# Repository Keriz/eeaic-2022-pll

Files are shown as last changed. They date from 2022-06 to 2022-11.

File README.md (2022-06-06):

# EEAIC 2022

Repository for documentation purposes of our project in the ETHZ course EEAIC, edition 2022.

We implemented the paper from Faroni et al. [1] to implement a Class-D VCO as part of a whole PLL.
Overall , we achieved a FoM @ 10 MHz of -190.14 dBc/Hz, with a total power budget of less than 4mW and a reference clock of 31.25MHz.

[1] L. Fanori and P. Andreani, "Class-D CMOS Oscillators," in IEEE Journal of Solid-State Circuits, vol. 48, no. 12, pp. 3105-3119, Dec. 2013, doi: 10.1109/JSSC.2013.2271531.

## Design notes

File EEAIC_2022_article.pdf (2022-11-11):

# EEAIC 2022 PLL - Final report

Xi Chen, Kyuik Cho, Garðar Eðvaldsson, Marwan Abdelaziz Ibrahim, Guillaume Thivolet

I. INTRODUCTION
This paper presents the implementation of a Phase-Locked Loop (PLL) in the TSMC 65-nm CMOS process based off the Class-D oscillator introduced by Fanori and Andreani in [1]. Class-D oscillators produce less phase noise compared to the class-B/C architectures for the same power consumption, at the expense of higher power supply than their counterparts. This work looked at implementing a Class-D VCO in a realistic PLL design where nonidealities were also taken into account. Current consumption, phase noise and figure-of-merits were derived and compared with the reference paper. The PLL runs at a supply voltage of 1.2V with a total power consumption of 3.837mW, with the VCO consuming 1.947mW which is substantially lower than the 4mW reported in the reference paper. The VCO exhibits a phase noise of -141.312 dBc/Hz at 10MHz, with a tuning range of 4%.

II. DESIGN SPECIFICATIONS
In order to design a realistic design, some metrics needed to be chosen.
Parameter | Value | Unit
fvco | 4 | GHz
fref | 31.25 | MHz
Ptot | <4 | mW
F oMV CO | <-191 | dBc/Hz
ϕn,vco @ 10MHz | <-143.5 | dBc/Hz

TABLE I: Initial design criteria for the PLL

III. PLL DESIGN AND COMPONENTS.
We aimed for a Type-II PLL using a fully analog control circuitry. In the following subsections, we will go through the choice of the components used for the realisation of the design.
PFD | Charge
Pump | LPF

1/128

VCO

REF
31.25MHz

FEED

4GHz

Vout | Vcont

QA

QB

Class-D CMOS Oscillator

Fig. 1: Block diagram for the PLL design.

A. Phase Frequency Detector (PFD)
The PFD, inspired from [2], has a role of generating switch signals Qa and Qb for the charge pump depending on which

Fig. 2: PFD Schematic

clock is lagging or leading. Those states are generated on rising edges of Clkref and Clkdiv respectively. If Clkref is leading, we first generate a pulse Qa that is pushing current into the low pass filter to raise the VCO control voltage Vcont. If Clkdiv is rising first, Qb is turned on first and the charge pump will pull current to ground, decreasing Vcont. The pulses are reset when the other clock has a rising edge.

B. Charge Pump (CP)

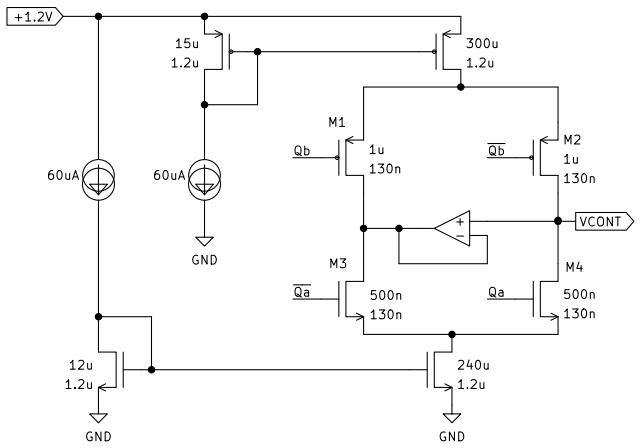
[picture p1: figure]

Fig. 3: Charge Pump Schematic

As we can see in Fig. 3, a simple current steering concept was used in order to keep a constant current flow at all times for better output control. Upon Qa being high, the transistor M1 turns off and M3 is turned on, injecting current to the loop-filter. Upon Qb being high, it would have the opposite to Qa, turning off M3 and turning M4 on, depleting current from the loop-filter as it would be connected to ground. If Qa and Qb are both off, the left branch is still drawing current. This keeps the Vds node voltages of the PMOS and NMOS current sources transistor constant. This is necessary in order to keep the parasitic capacitance Cds of all transistor fully charged at all times, instead of depleting them due to the charge sharing nature of the capacitance in the loop-filter. In order to do so, the operational amplifier between the two branches keeps Vcont constant on both sides of the branches and keeps the parasitic capacitances charged. Therefore the charge pump and the loop-filter charge sharing is minimised which improves dynamic current matching. CP phase noise is primarily given by the channel thermal noise component of the current source ¯i
2
d = 4KT γgm.
C. Loop Filter (LF)
In order to ensure stability of the PLL loop dynamics described in section V, a higher order filter needs to be used. In this project, a simple 2nd order filter was designed using two capacitors and a resistor.

Fig. 4: 2nd order loop filter schematic

D. Frequency Divider (FD)

Fig. 5: Frequency divider block diagram

The frequency divider is using 3 daisy chained TSPCs with a division factor of 2, along with 4 daisy chained flip-flops with a division factor of 2. This gives in total a division factor of 2

7 = 128. The full schematic and operation is available in Appendix VIII-B.
The TSPC blocks are responsible for frequency division of high frequency clock signals, whereas the flip-flops are more suitable for slower signals, since the TSPC topology fails at slower clock frequencies due to high leakage currents. Finally, the output of the last divider stage goes into the PFD block, which completes the PLL Loop.

IV. CLASS-D VCO
The main building block of every PLL is the VCO. This project was aimed at integrating the Class-D oscillator as envisioned by [1] and benchmark its performances in a Type-II PLL.
In Fig. 6 is the schematic of the implemented VCO for the PLL. It shows discrepancies from the ideal VCO as we needed to account for parasitics in order to simulate a realistic environment.
1) Inductor Model: In order to simulate a realistic inductor in the VCO, a simplified model needed to be realised. By choosing an inductance of 500pH, and a Q-factor of 15 (which is realistic for a moderately designed inductor), other parasitic elements can be calculated as follows. The quality factor for an ideal inductor is:
Q =

ωL
R

(1)

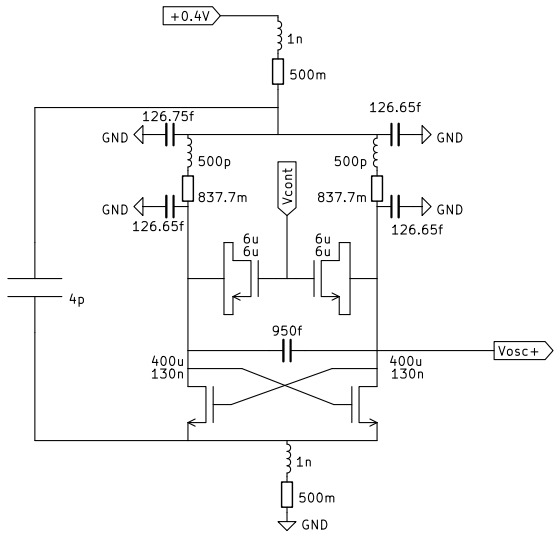
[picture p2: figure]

Fig. 6: Class-D VCO Schematic

and by simplifying for R, we can calculate the parasitic resistance:
R =

ωL
Q
= 837.7mΩ | (2)

where ω = 2 · π · fosc, where fosc = 4GHz. Now we state that we have a oscillating harmonic at 5 times the oscillation frequency, and using:

ωH = 5 · ω =

1
√
LC | (3)

and solving for C, we get:

C =

1
ω

2
HL
= 126.65fF | (4)
2) Wire Bonding: Because of the severe supply pushing of the Class-D oscillator, it is of extreme importance to simulate the off-chip wire bonding instead of using a clean power supply in order to see the supply pushing effect on the output of the oscillator. In order to simulate a realistic wire bonding, an inductor of 1nH and a resistor of 500mΩ were attached on both ground and Vdd. Along with the off-chip parasitics, a capacitor of 4pF was added between the rails in order to suppress the harmonics introduced by the parasitics.
A. Tuning Range
In order to control the oscillation frequency of the oscillator, a way to change either the inductance or the capacitance of the LC tank has to be developed. In a real design, it is extremely hard to change the inductance as the inductor has a fixed size (area of metal on a substrate), so the easiest and most-common choice is to vary the capacitance of the LC-tank using a socalled varactor. Different configurations can be used in order to adjust the capacitance of the LC-tank. In this report, two transistors were chosen in a back-to-back configuration, by using their parasitic capacitance when operated in the triode region. The control voltage from the charge pump (Vcont) was connected to the gates of both transistors, and their bulk (drain, source and body) were connected to the differential output ports of the VCO. By doing so, an acceptable tuning range could be chosen.

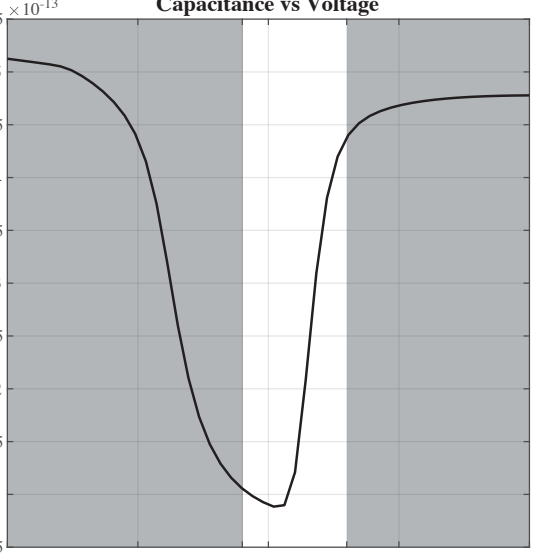
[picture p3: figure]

-2 | -1 | -0.2 0 | 0.6 | 1 | 2
V

## gs [V]

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
## Capacitance [F]

# 10⁻¹³ Capacitance vs Voltage

Fig. 7: Capacitance of tuning varactors plotted over applied voltage

As we can see from Fig. 7, the white area of the capacitance curve is the available working range of capacitance with the given oscillation amplitude and the given control voltage amplitude. Due to the asymmetrical nature of the Class-D oscillations, the simple formula ωosc = √

1
LC cannot be used
in order to determine the running frequency of the oscillator. A more elaborated analysis needs to be carried out [1], but a simple simulation can also suffice by simply sweeping the control voltage and simultaneously plotting the oscillation frequency fosc.
As we can see in Fig. 8 the range varies from [3.9-4.05] GHz, with the target frequency achieved when Vcont ≈ 630mV, resulting in a gain factor of Kvco = 220MHz/V. Special care needs to be taken when defining the range of Vcont, since it can sacrifice the closed loop stability of the PLL if too low.
B. Phase Noise and FoM
Phase noise can be described as random phase fluctuations at the output of the VCO. These fluctuations are caused by time-domain instabilities usually referred to as phase jitter. The phase noise is relative to the carrier frequency (fosc = 4GHz). As we can see in Fig. 9, we see the two main noise contributors to the phase noise, namely the upscaled flicker noise and the upscaled thermal noise. The corner where the thermal noise starts dominating over the flicker noise has been meticulously chosen at 180kHz. This will depend on the overall noise of the PLL’s performance which will be discussed better in section VI-A.

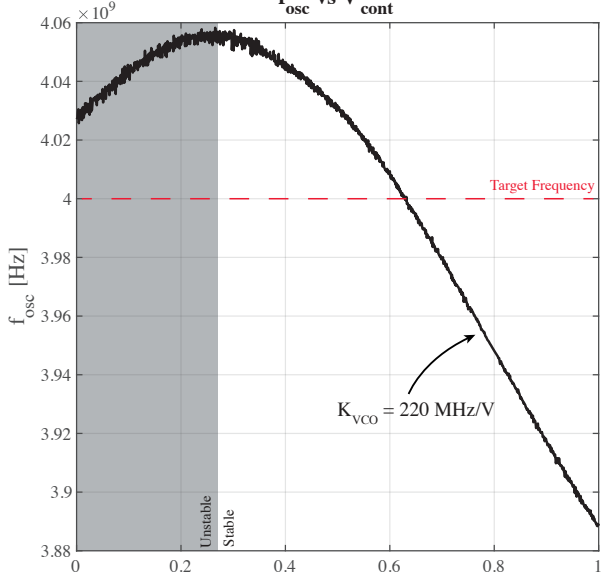
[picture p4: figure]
osc [Hz]; Unstable; Stable; KVCO = 220 MHz/V; Target Frequency

0 | 0.2 | 0.4 | 0.6 | 0.8 | 1

## Vcont [V]

10⁹ | f osc vs Vcont

Fig. 8: Oscillation frequency plotted over control voltage.

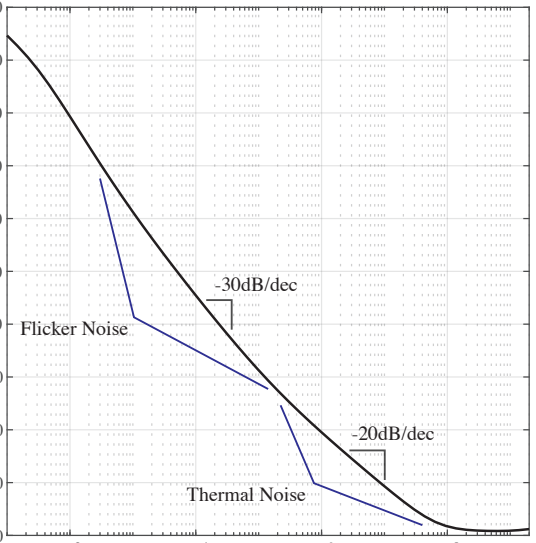
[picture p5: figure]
-20dB/dec; -30dB/dec; Flicker Noise; Thermal Noise

10² | 10⁴ | 10⁶ | 10⁸

## Offset Frequency [Hz]

-160

-140

-120

-100

-80

-60

-40

-20

0

20

40

## Phase Noise [dBc/Hz]

# VCO Phase Noise

Fig. 9: Phase noise of the Class-D VCO

In order to compare the VCO design with other designs on the market, the best benchmark is the Figure-of-Merit (FoM). Which compares the phase noise with the power needed to achieve that noise level. The FoM yields:

F oMvco = L(∆f) − 20log
fosc
∆f

+ 10log
Pvco

1mW
(5)
= −190.4dBc/Hz | (6)

where L(∆f) = −141.312dBc/Hz, ∆f = 10MHz, fosc =

4GHz and Pvco = 1.947mW.

C. PVT Variations

Due to PVT (Process-Voltage-Temperature) variations the PLL behaves differently than under ideal conditions. For the operation of the PLL, the biggest concern is the frequency tuning range of the VCO (see Fig. 10). In order to keep things simple, the only PVT variations of interest were the ones that had the most impact on the tuning range of the VCO. After running a bulk of initial simulations, three corners were chosen which displayed the highest range of tuning range.

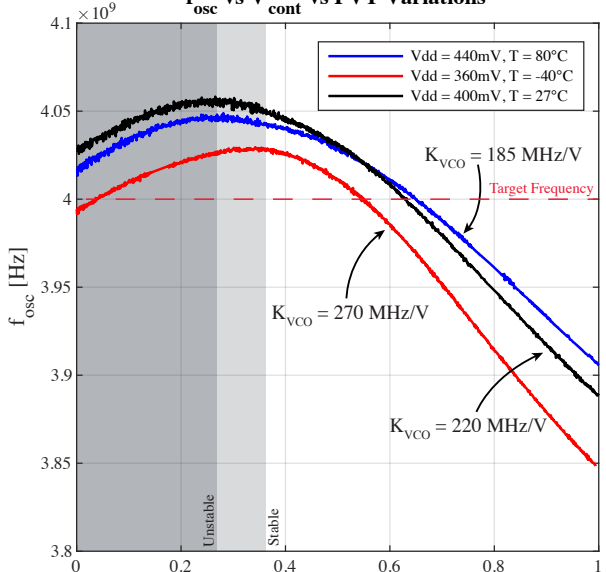
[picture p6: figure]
osc [Hz]; KVCO = 270 MHz/V; KVCO = 185 MHz/V; Target Frequency; KVCO = 220 MHz/V; Unstable; Stable

0 | 0.2 | 0.4 | 0.6 | 0.8 | 1

## Vcont [V]

10⁹ f

# osc vs Vcont vs PVT Variations

Vdd = 440mV, T = 80°C Vdd = 360mV, T = -40°C Vdd = 400mV, T = 27°C

Fig. 10: Frequency tuning range in terms of PVT variations.

As we can observe on Fig. 10, which shows the best and worst case scenarios for the PVT variations, the frequency gain of the VCO KV CO is heavily affected. This KV CO difference will impact the PLL noise characteristics and the loop bandwidth would ideally have to be adjusted again to match the new crossover frequency between the VCO and CP noise curves. However, it is possible to change ICP accordingly to conserve the same noise figure. Under PVT variations the frequency tuning crosses our target frequency of 4GHz, which indicates that the PLL will be able to lock under any conditions. It might however experience longer locking times at lower KV CO. We also see that in order for the PLL’s closed loop to be stable, the voltage control range must be limited between [0.35V-1V] when the VCO reaches higher KV CO while having a wider range of [0.25V-1V] for smaller KV CO.
As we can see from Fig. 11, the main change in phase noise because of PVT variations happens in the flicker noise region. That proves to be non-crucial since the transfer function for the noise of the VCO attenuates the flicker noise sufficiently.

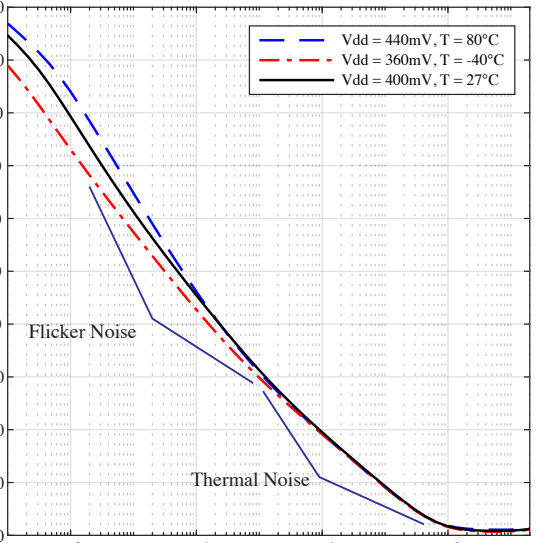
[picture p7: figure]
Vdd = 400mV, T = 27°C; Thermal Noise; Flicker Noise

10² | 10⁴ | 10⁶ | 10⁸

## Offset Frequency [Hz]

-160

-140

-120

-100

-80

-60

-40

-20

0

20

40

## Phase Noise [dBc/Hz]

# VCO Phase Noise and PVT Variations

Vdd = 440mV, T = 80°C Vdd = 360mV, T = -40°C

Fig. 11: Phase noise dependent on PVT variations

KVCO | Voltage | Temperature | Library
Nominal | 400mV | 27°C | tt_lib
High | 360mV | -40°C | sf_lib
Low | 440mV | 80°C | sf_lib

TABLE II: Chosen PVT corners for all simulations

V. PLL LOOP DYNAMICS
The PLL closed-loop dynamics (type-II system) is unstable as such, due to the non-existent phase margin as constant phase is -180°. This is usually compensated by the addition of a resistor R in between the CP and the VCO, which adds a zero for the loop stability. Additionally, we add another capacitor C2 in parallel to RC1 which is used to minimize the ripple on the control voltage.

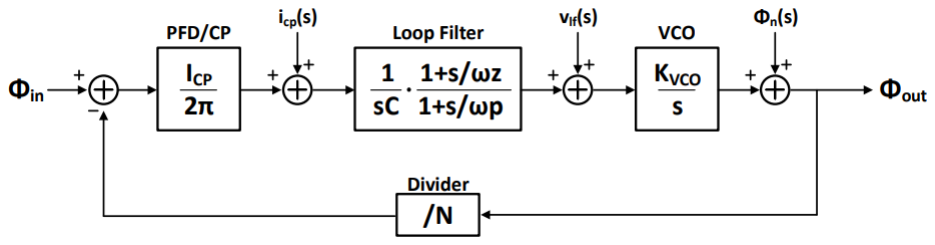
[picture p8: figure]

Fig. 12: PLL block diagram of transfer function

Ignoring the charge sharing capacitor, the closed-loop transfer function in the Laplace domain is given by:

HCL(s) =

IcpKV CO
2πC1

(sRC1 + 1)

s

2 +

Icp
2π

KV CO
N Rs +

Icp
2πC1

KV CO
N

(7)

We identify it to a second order system which is in the general case expressed as:

H(s) = | ωn
| 2
s

2 + ζωns + ωn
2

(8)

We define ωn and ζ in eq. 8 as such¹ :

ωn =

r
ICP
2πC1

KV CO
N

ζ =

R
2

r
ICP C1
2π

KV CO
N

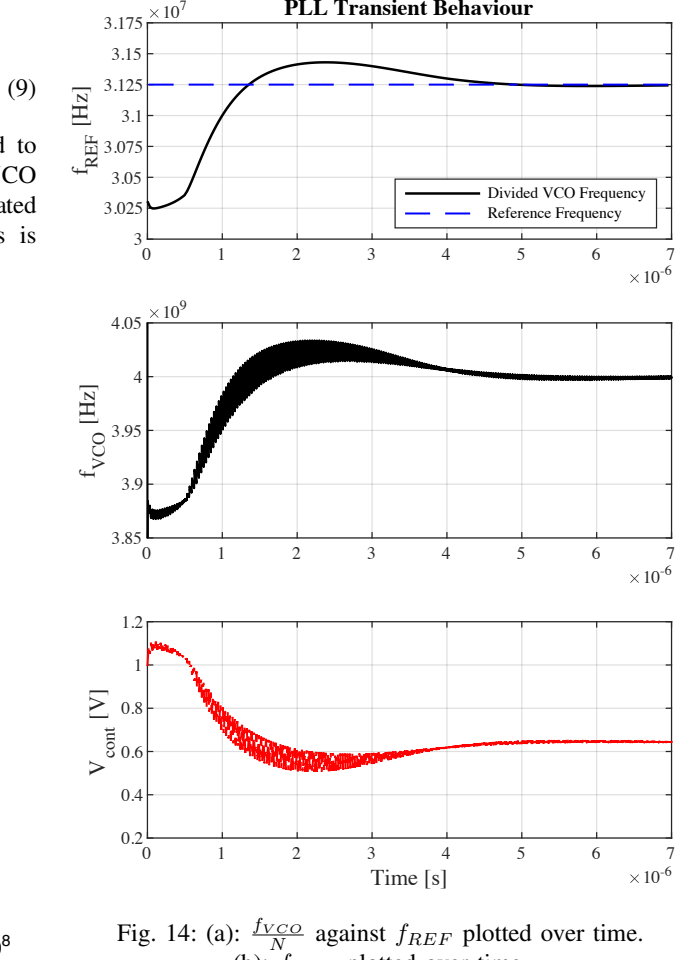
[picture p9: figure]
fREF [Hz]; Divided VCO Frequency Reference Frequency; fVCO [Hz]; Time [s]; Vcont [V]; Fig. 14: (a): fV CO N; against fREF plotted over time.

The PLL loop bandwidth of 281 kHz was optimized to match the crossover frequency of the charge pump and VCO phase noise curves and with a trade off between integrated jitter and lock time. The detailed optimisation process is explained in section VI.

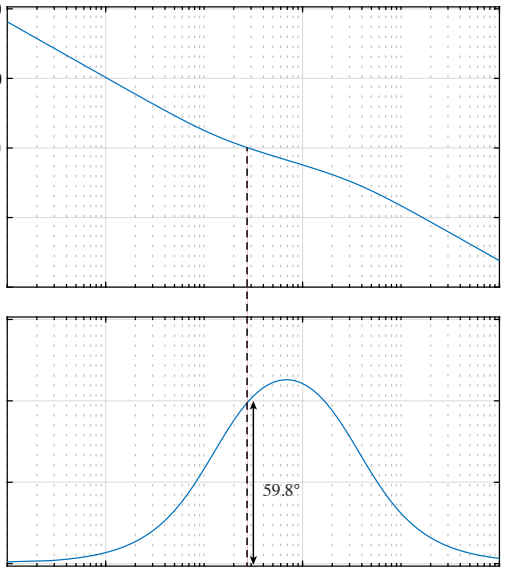
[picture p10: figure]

-100

-50

0

50

100

## Magnitude (dB)

10⁴ | 10⁶ | 10⁸

-180

-150

-120

-90

## Phase (°)

## PLL OL TF - Pm = 59.8° @ 281kHz

## Frequency (Hz)

Fig. 13: PLL Open Loop Dynamics

As we can see from Fig. 13, the open loop gain of the PLL dynamics has a phase margin of 59.8°at 281kHz.

VI. RESULTS

We ran a transient simulation of the whole PLL using Cadence Spectre. The resulting graphs are shown below.
As seen in Fig. 14, our PLL locks with success on the target frequency with a lock time of 5.05µs. In the further subsections, we will introduce the noise figures, the overall Figure-of-Merit for the entire PLL as well as the design resilience against PVT variations.
A. Noise
The biggest concern of a PLL is it’s noise contribution. Every block of the PLL introduces it’s own noise transfer functions, which in return contributes to the overall noise level of the PLL. In this work, the noise contribution of the reference clock is considered out of scope.

1KV CO = 220MHz/V, ICP = 1.2mA, N = 128, C1 = 233.9pF, R = 5.05KΩ

# 10⁷ PLL Transient Behaviour

(b): fV CO plotted over time. (c): Vcont plotted over time.

As we can see from Fig. 15, the the noise from the charge pump and and the VCO are nicely optimised in order to minimise the overall noise. Because of that, the overall noise is solely dominated by the loop-filter noise. Since the loop filter only consists of passive elements, it introduces a fixed noise floor that provides a hard limit to what can be achieved when it comes to noise optimisation.

B. Figure-of-Merit
By integrating the total noise from Fig. 15, the absolute RMS-jitter can be computed. The absolute RMS-jitter is defined as:

σ

2
t,P LL =

1
2π

2f

2/0 Z ∞

0

L(f) df | (10)

and the FoM of the PLL is defined as: F oMP LL = 10 log σt,P LL 1s
2 PP LL
1mW | (11)

With σt,P LL = 79.2fs and PP LL = 2.8974mW we get an FoM value of:

F oMP LL = −257.4dBc/Hz | (12)

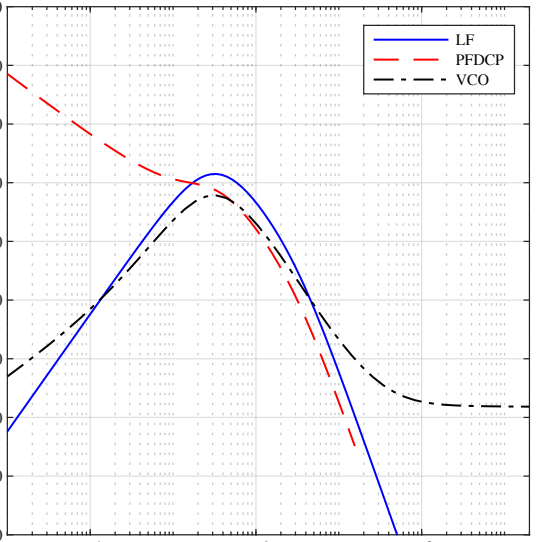
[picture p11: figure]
LF PFDCP VCO

10⁴ | 10⁶ | 10⁸

## Frequency [Hz]

-180

-170

-160

-150

-140

-130

-120

-110

-100

-90

## Phase Noise [dBc/Hz]

# PLL Phase Noise

Fig. 15: All noise contributions in the PLL.

C. PVT Variations

One of the biggest design criteria of every PLL design, is its robustness to PVT variations. By choosing the three important corners mentioned in Tab. II, we can predict the overall noise performance of the PLL.

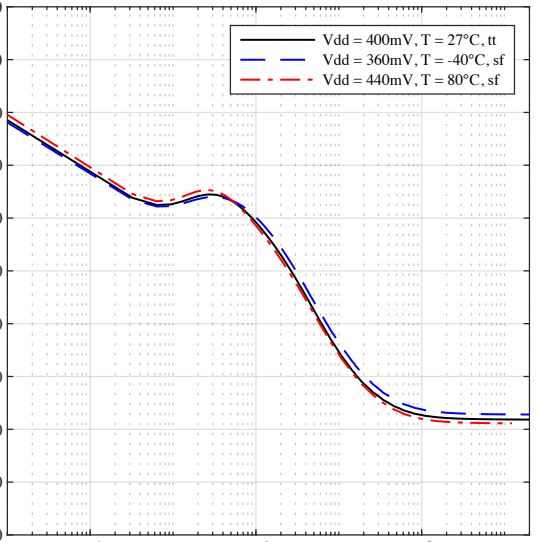
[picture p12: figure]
Vdd = 440mV, T = 80°C, sf

10⁴ | 10⁶ | 10⁸

## Frequency [Hz]

-180

-170

-160

-150

-140

-130

-120

-110

-100

-90

-80

## Phase Noise [dBc/Hz]

# PLL Phase Noise with PVT Variations

Vdd = 400mV, T = 27°C, tt Vdd = 360mV, T = -40°C, sf

Fig. 16: Total noise at different PVT corners

As we can see in Fig. 16, there is quite some noise deviation between the different corners.

KVCOCorner | Total Jitter | FoMPLL
Nominal | 79.2 fs | -257.40 dBc/Hz
High | 81.3 fs | -258.65 dBc/Hz
Low | 81.21 fs | -256.44 dBc/Hz

TABLE III: Total Noise of PLL w.r.t. to PVT variations

VII. CONCLUSION

This paper has presented a simple Type-II PLL design with a Class-D VCO [1]. The simulations have shown reasonable performance under all corner cases of interest and a decent FoM. Further improvements include increasing the tuning range of the VCO for a broader, which could entail adding coarse tuning, along with looking into more varactor topologies in order to tailor the tuning range even further than this present work does.

VIII. APPENDIX

A. Inverted Varactors

Instead of connecting Vcont to the gates of the two transistors, the transistors can be "turned around", and by connecting Vcont to their bulk (drain, source and body) and connecting the gate to the differential outputs (see Fig. 17) achieving a different frequency operating range.

Fig. 17: Two different varactor topologies.
Left: MOSFETs with Vcont wired to the common gates. Right: MOSFETs with Vcont wired to the common bulks.

Now by examining the tuning range of the VCO in Fig. 18, we can see substantial differences between the two varactor placements.
As we can see in Fig. 18, the voltage range of the control voltage is severely reduced compared to the varactor structure used in the current design. We can also see that in order to ensure closed loop stability of the PLL, the control range of Vcont must be meticulously chosen in order not to introduce a negative KV CO in the control loop.
B. TSPC

The True Single-Phase Clocking (TSPC) divide by 2 based circuit is shown in figure 19. It is a positive-edge triggered D-flip-flop with TSPC logic [3] which inverted output is tied to the D input.
We perform an analysis of the circuit to understand its functionality. We will initially assume that Q and CLK are 0. Node A and B will both be 1 and Q output will not change. On a rising edge of CLK, A will be floating. Node B will be

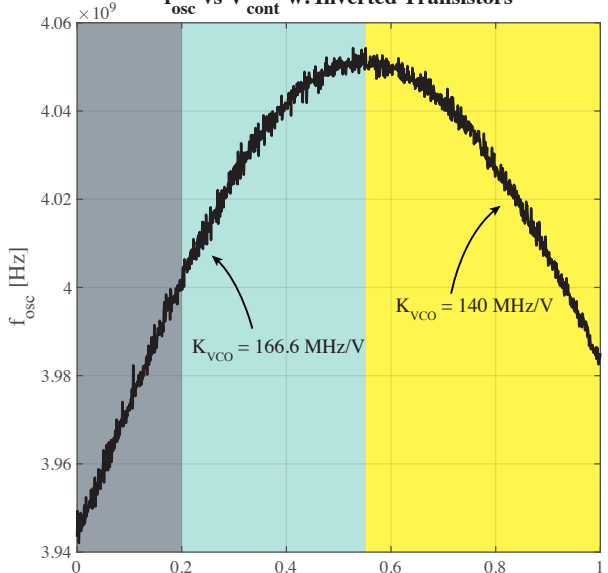
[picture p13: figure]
osc [Hz]; KVCO = 140 MHz/V; KVCO = 166.6 MHz/V

0 | 0.2 | 0.4 | 0.6 | 0.8 | 1

# Vcont [V]

10⁹ f

# osc vs Vcont w. Inverted Transistors

Fig. 18: Frequency behaviour of inverted varactors in the

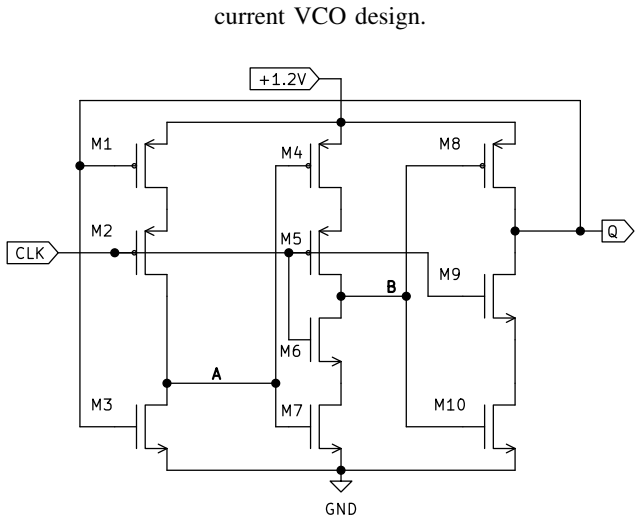
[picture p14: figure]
current VCO design.

Fig. 19: True Single-Phase Clocking (TSPC) used as a frequency divider

pulled to 0 which raises Q to 1. This change of output has no retroactive effect on the current state.
Now that Q is high, when CLK goes low the node A will have the logic value 0 and B will be floating, keeping the charge from last state, so the output stays constant. Finally, on a rising edge of CLK, node A will still be 0 and B still has the last state of 0. This pulls the Q output to 0, which effectively halves the clock period. This topology achieves relatively high speeds with low power dissipation.

REFERENCES
[1] Luca Fanori and Pietro Andreani. “Class-D CMOS Oscillators”. In: IEEE Journal of Solid-State Circuits 48.12 (Dec. 2013). Conference Name: IEEE Journal of Solid-State Circuits, pp. 3105–3119. ISSN: 1558-173X. DOI: 10.1109/JSSC.2013.2271531.
[2] Behzad Razavi. RF microelectronics. 2nd ed. Upper Saddle River, NJ: Prentice Hall, 2012. ISBN: 978-0-13-713473-1.
[3] Behzad Razavi. “TSPC Logic [A Circuit for All Seasons]”. en. In: IEEE Solid-State Circuits Mag. 8.4 (2016), pp. 10–13. ISSN: 1943-0582. DOI: 10.1109/MSSC.2016. 2603228. URL: http : / / ieeexplore . ieee . org / document / 7743122/ (visited on 06/01/2022).

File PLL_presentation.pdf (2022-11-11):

3.6.2022 | 1

## PLL based on a Class-D CMOS Oscillator

Xi Chen, Kyuik Cho, Garðar Eðvaldsson, Marwan Abdelaziz Ibrahim, Guillaume Thivolet

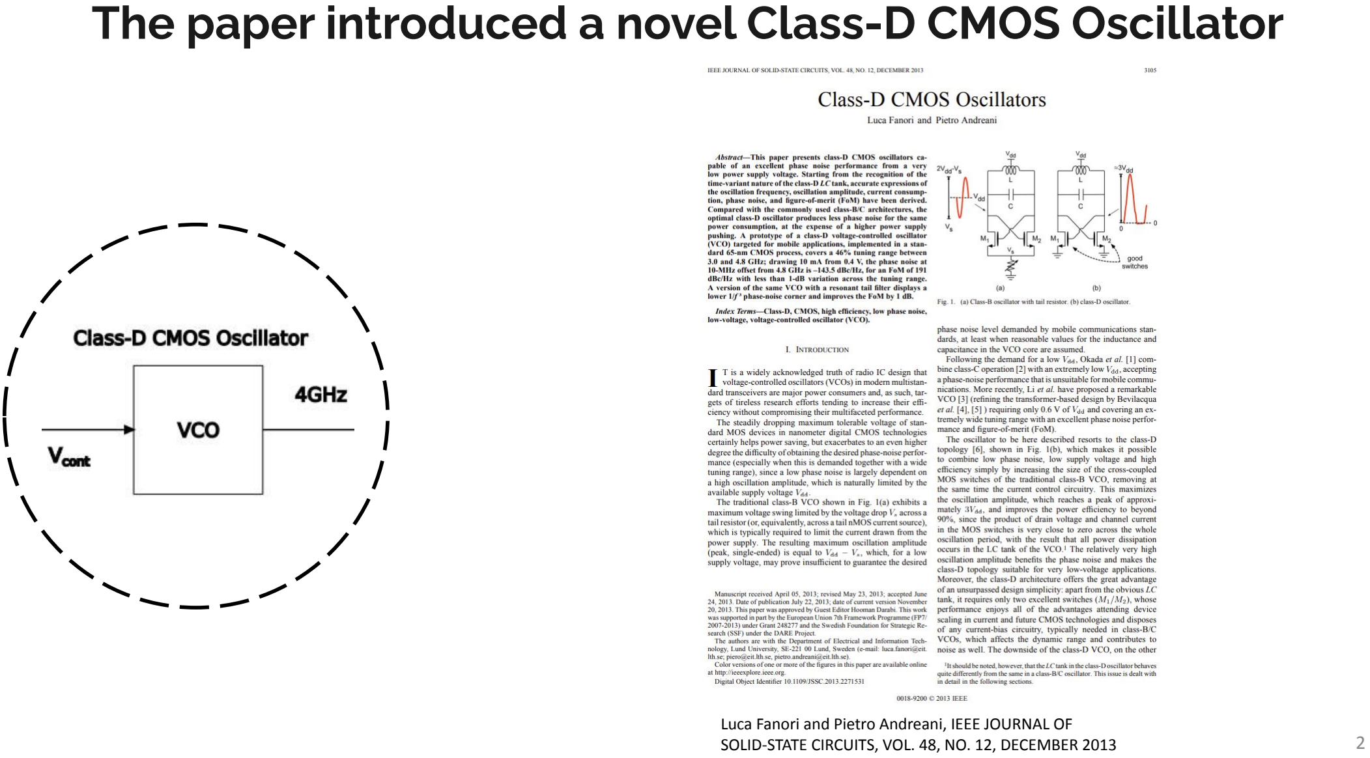
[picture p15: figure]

## The paper introduced a novel Class-D CMOS Oscillator

Luca Fanori and Pietro Andreani, IEEE JOURNAL OF SOLID-STATE CIRCUITS, VOL. 48, NO. 12, DECEMBER 2013

## Our goal was to implement the VCO as part of a whole PLL

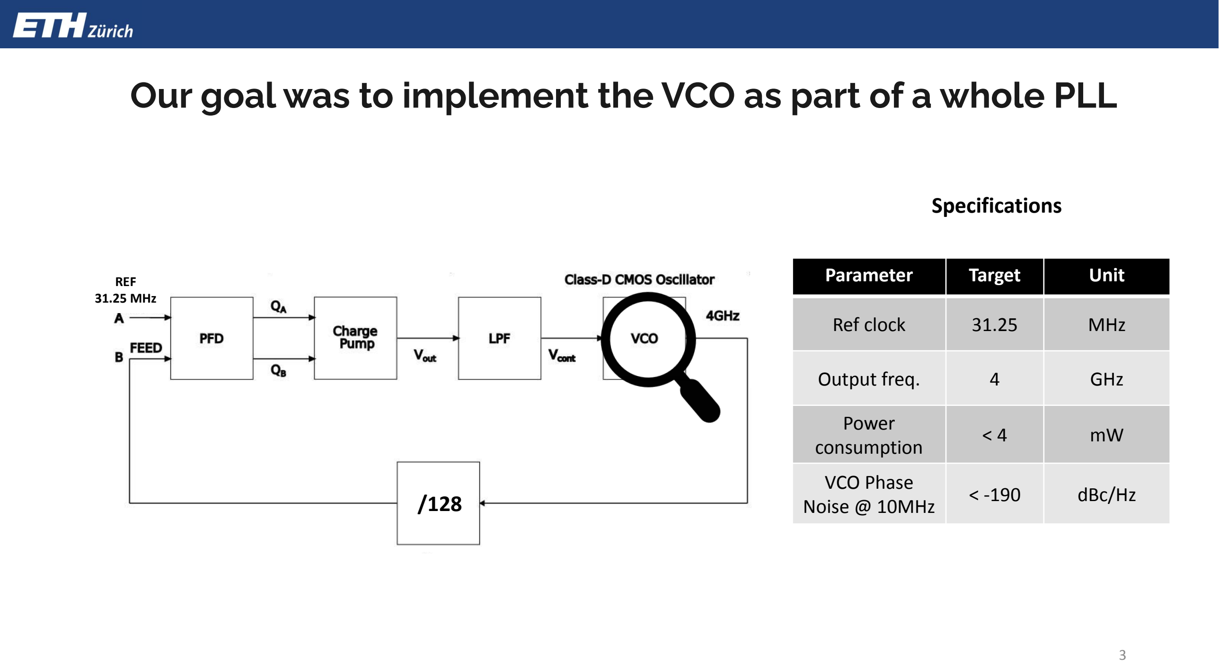
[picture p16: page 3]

/128

Specifications

Parameter | Target | Unit
Ref clock | 31.25 | MHz
Output freq. | 4 | GHz
consumption | Power | < 4 | mW
VCO Phase Noise @ 10MHz | | < -190 | dBc/Hz

REF

### 31.25 MHz

## PLL – Overview

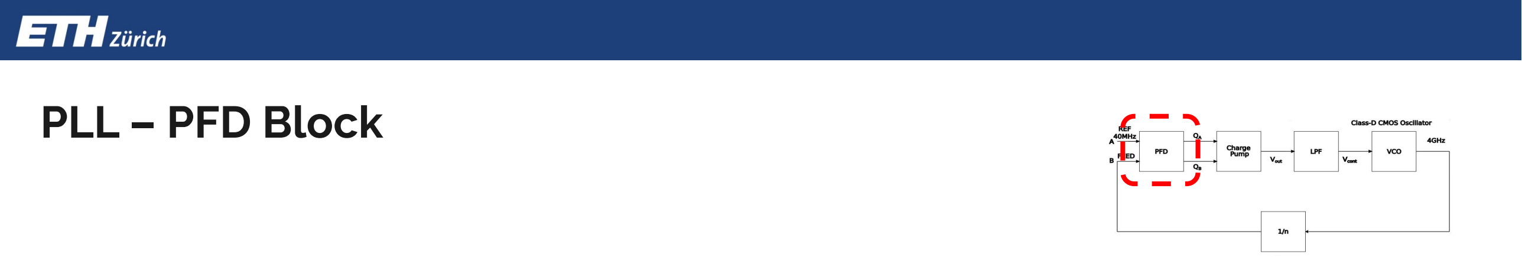
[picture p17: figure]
PLL – PFD Block

Phase Frequency Detector

- Generate control signals for the charge pump
- Two DFFs with their D input tied to +VDD, one clocked by the stable reference clock CLK_ref (31.25MHz) and the other by CLK_div (feedback from the VCO)

## PLL – Charge Pump Block

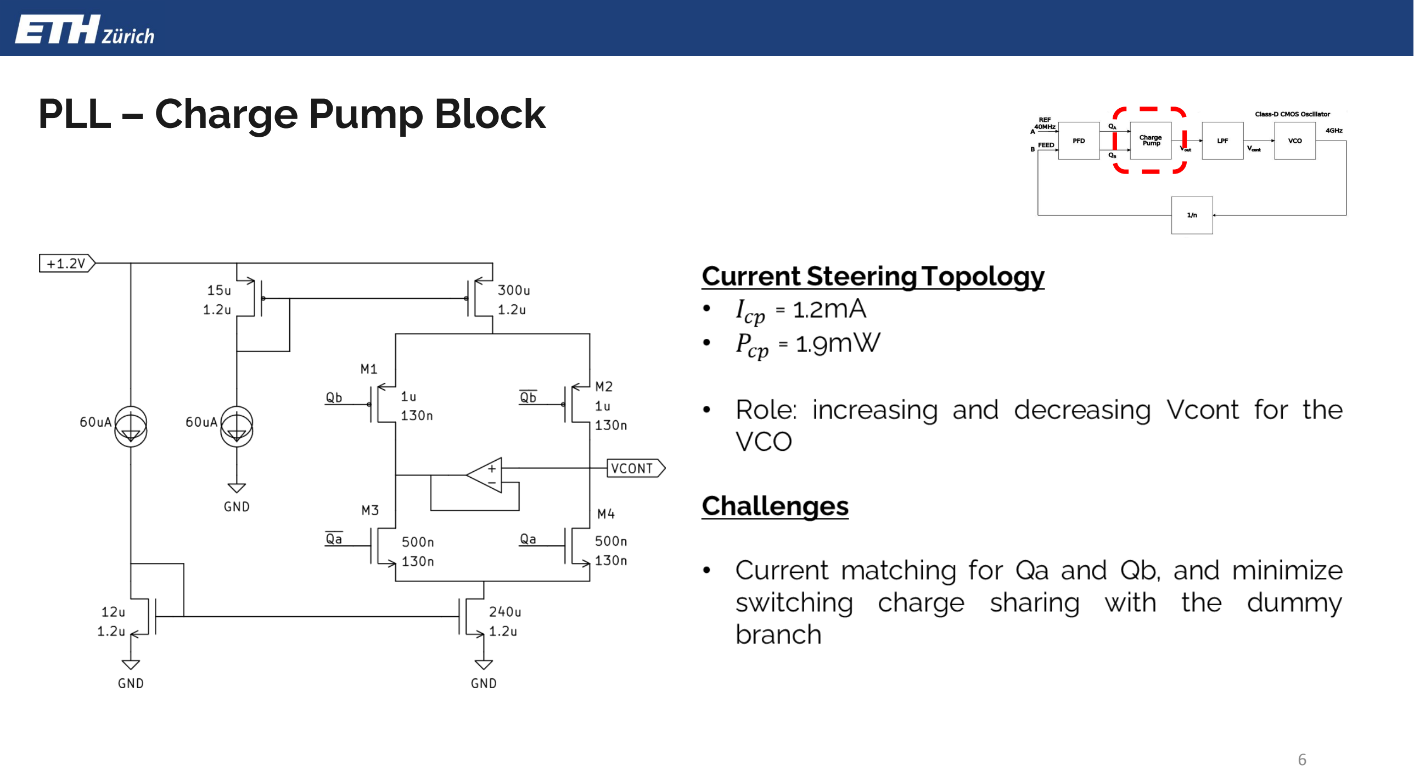
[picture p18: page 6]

## PLL – 2nd order LPF

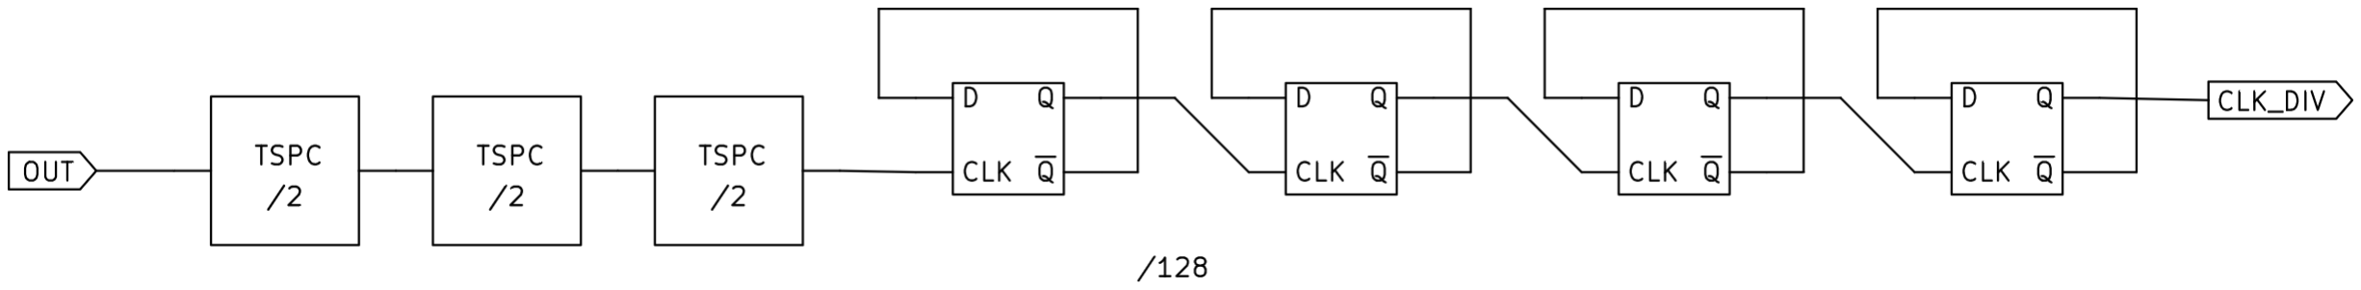
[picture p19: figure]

* TSPC available in appendix

High Frequency Switching | Lower Frequency Switching

## Ideal Class-D VCO

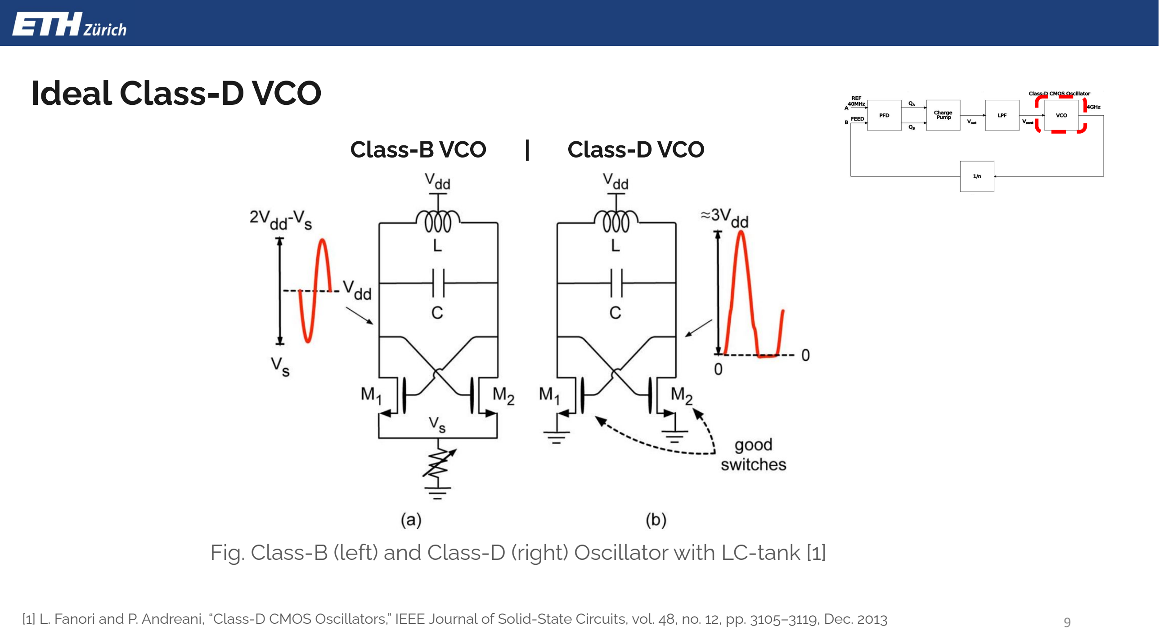
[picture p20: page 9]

Fig. Class-B (left) and Class-D (right) Oscillator with LC-tank [1]

[1] L. Fanori and P. Andreani, “Class-D CMOS Oscillators,” IEEE Journal of Solid-State Circuits, vol. 48, no. 12, pp. 3105–3119, Dec. 2013
Class-B VCO | | | Class-D VCO

## Ideal Class-D VCO

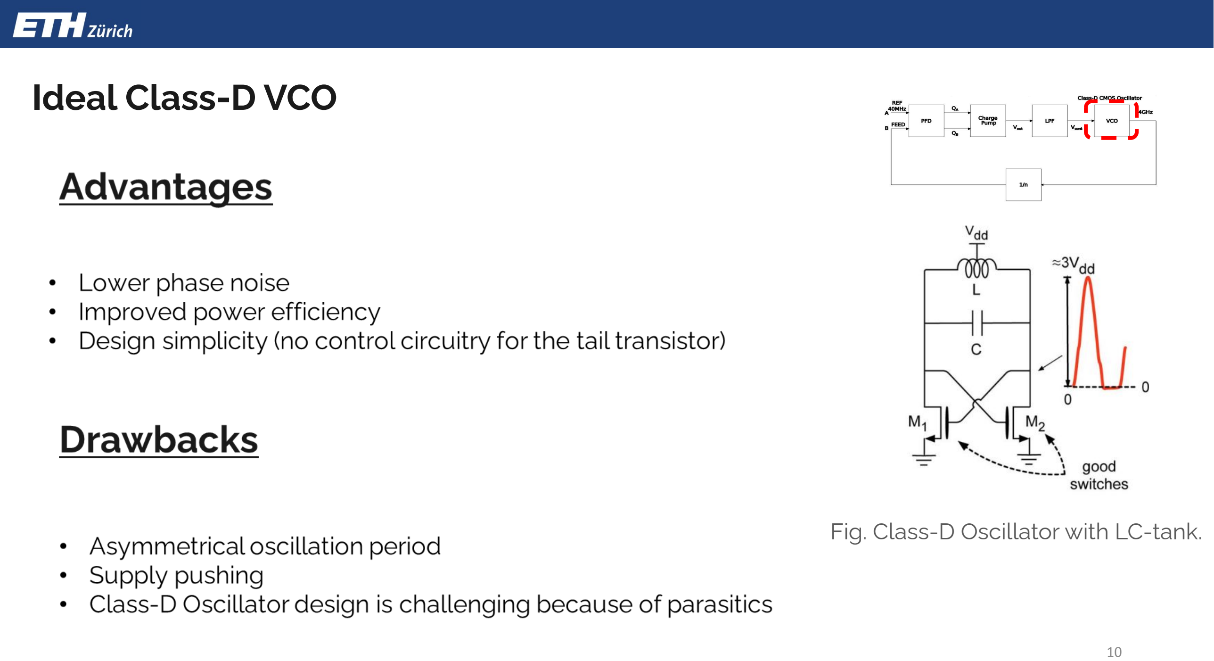
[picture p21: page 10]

Fig. Class-D Oscillator with LC-tank.

## Practical Class-D VCO Schematic

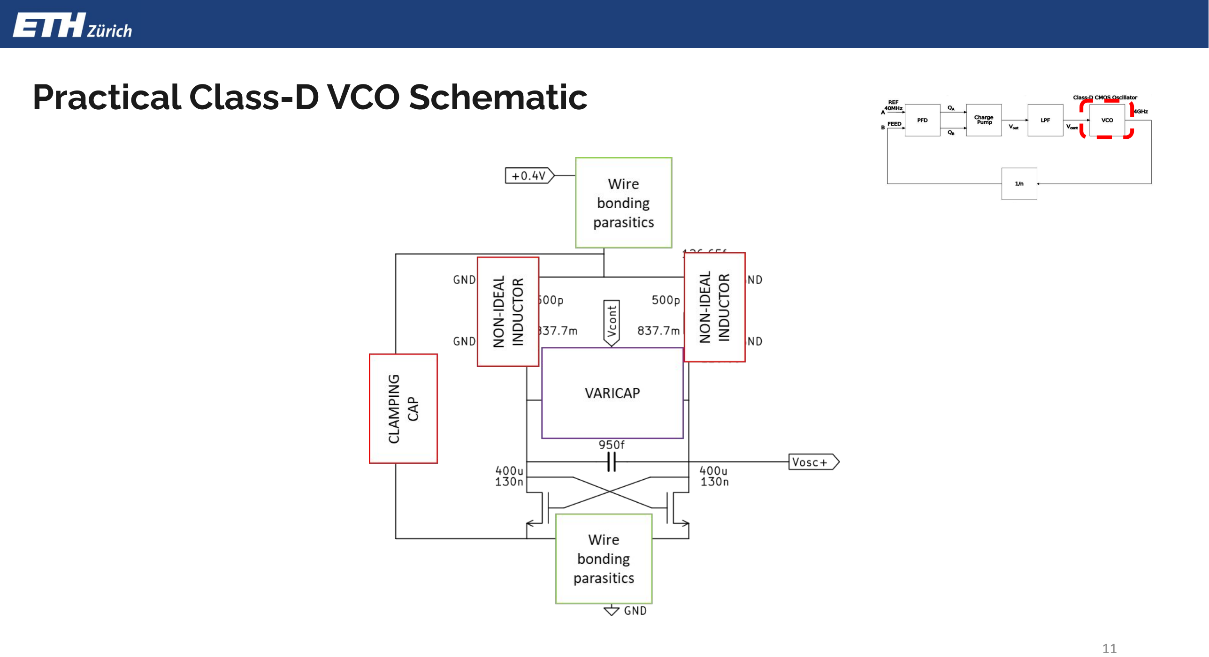
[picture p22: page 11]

## Practical Class-D VCO Schematic

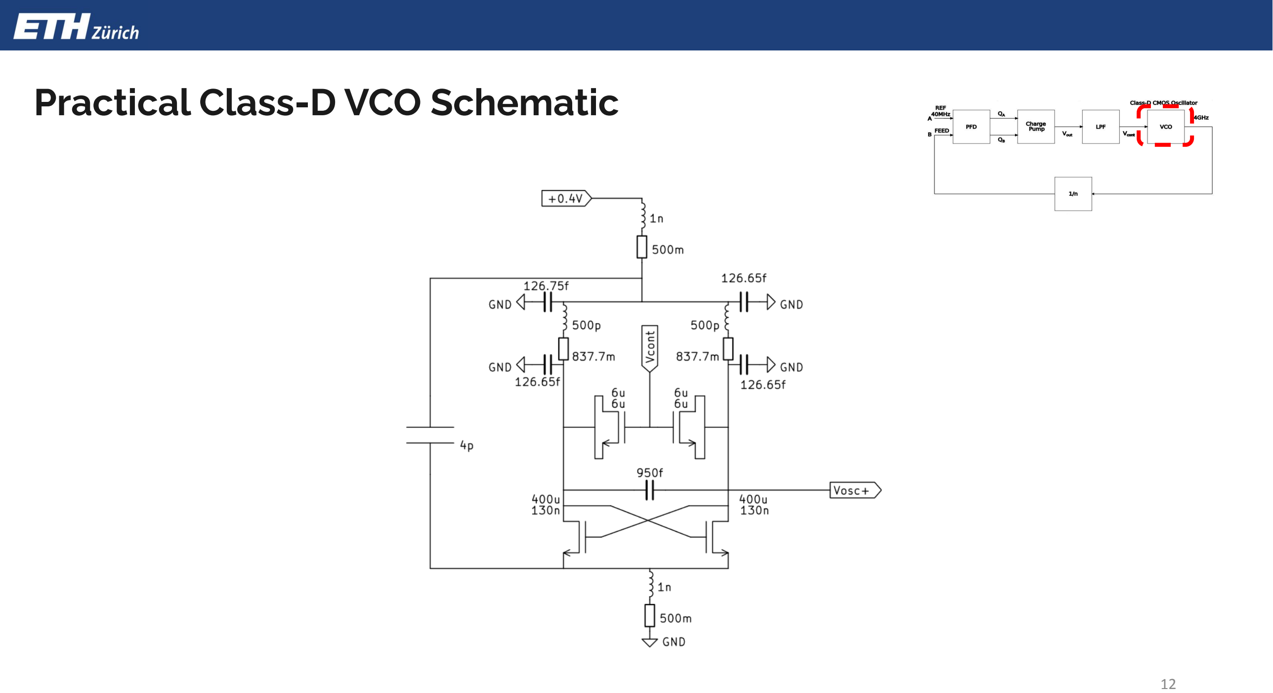
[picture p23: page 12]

## Practical Class-D VCO Schematic

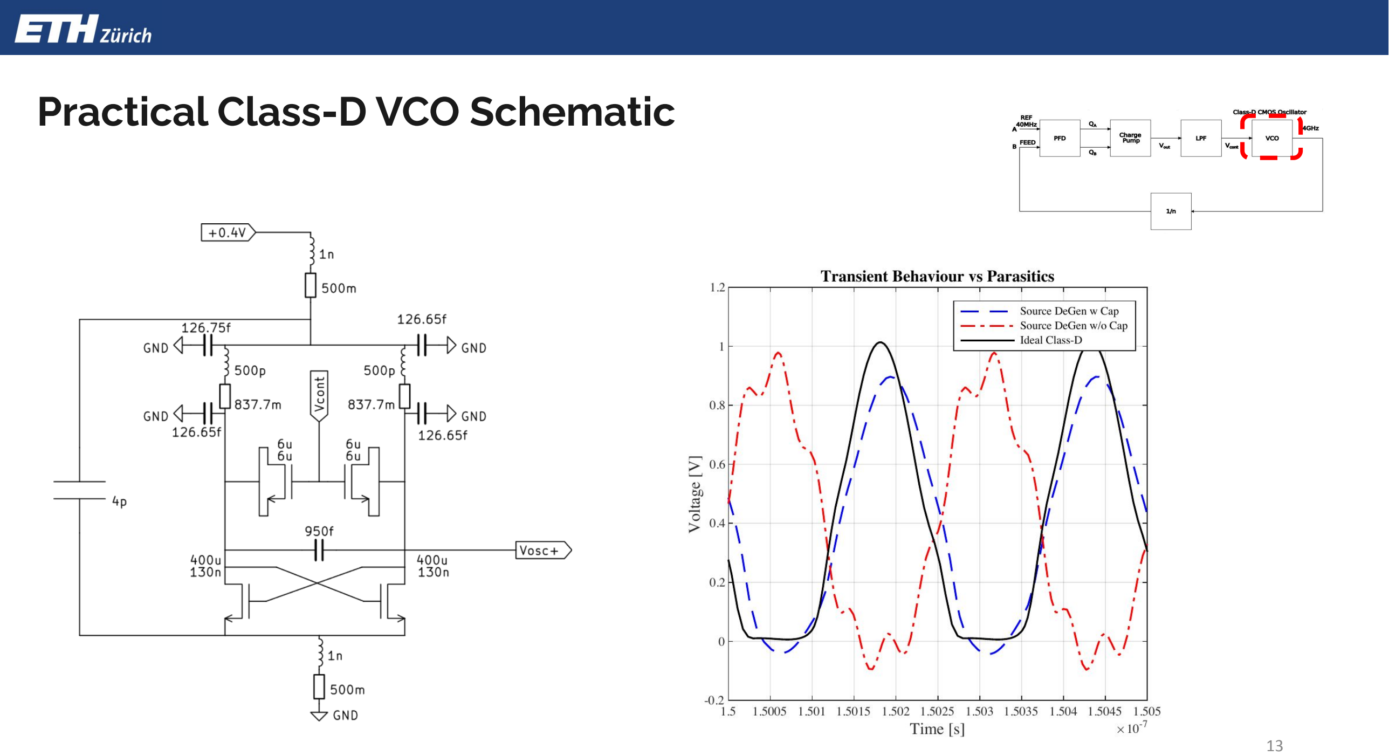
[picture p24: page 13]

## VCO - Varactor

## VCO - Varactor


## VCO - Figure of Merit


## VCO - Output Buffers


## PLL - Noise Contributions

To optimize noise, the noise contribution of each building block needs to be accounted for

## PLL - Noise Contributions

PLL Open Loop Transfer function

VCO noise transfer function

Loop filter noise transfer function

LPF

BPF

HPF

Charge Pump noise transfer function

## Results – Transient Simulation I


## PLL – Noise Simulation I


## PLL – Noise Simulation II


## Results – Transient Simulation II


## Results - PVT Variations – Phase noise of the VCO


- Negligible effects on VCO phase noise
- Biggest changes in flicker noise region
- Filtered out by VCO’s output transfer function

## Results - PVT Variations – Varactor w.r.t KVCO


## Results - PVT Variations – PLL Phase Noise


- Negligible effects on noise performance when
considering PVT variations
- Loop Filter dominates all noise plots

## Further possible improvements

- Charge pump
- Replace the ideal operational amplifier with a realistic design
- VCO
- Try different varactor topologies for improved KVCO
- Adding coarse tuning options to the cap bank for wider tuning range
- BW optimization
- VCO power↓, VCO noise↑with the same FoM
- Improve lock time
- Improve FoM

## Questions?

## Appendix – Inverted varactors

- Extremely small voltage range
- Easy to enter an unstable region of the PLL’s operating region
- Low Kvco

## Appendix – Inverted varactors PVT


## Appendix – Normal Varactors PVT


## Appendix – TSPC Schematic


## Appendix – Inductor Model

## Appendix – Transient Ripple of Vcont


## Appendix – PFD signals and charge sharing

## Appendix – PFD signals and charge sharing

| ISSCC 2015 L.Kong | VLSI 2017 T.Seong
Technology (nm) | 45 | 65
Architecture | Analog PLL | Analog PLL
Output Freq [Hz] Tuning Range [Hz] | 2.4G 2G to 3G | 3.008G
Mult. Factor, N | 106 | 64
Int. rms Jitter [fs] Int. Range [Hz] | 970 1K to 200M | 357 1K to 80M
Ref. Spur [dBc] | -65 | -71
Area [mm2] | 4 | 4.6
Power [mW] | 0.015 | 0.047

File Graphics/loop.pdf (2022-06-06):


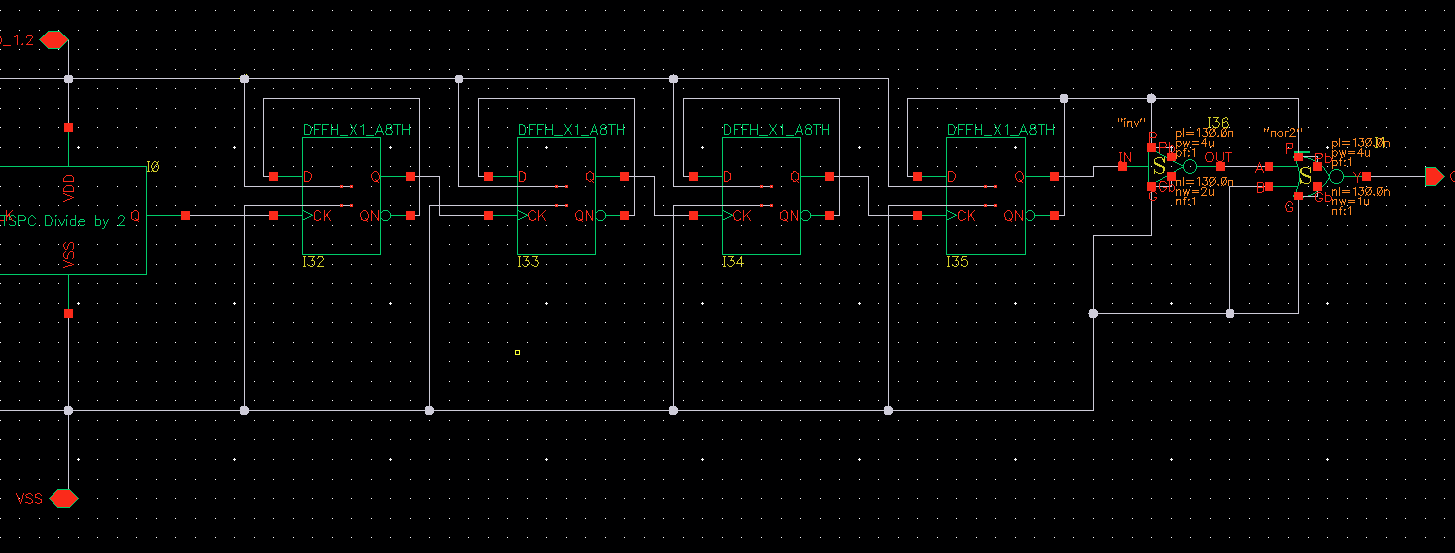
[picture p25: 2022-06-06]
Cadence/freq.png

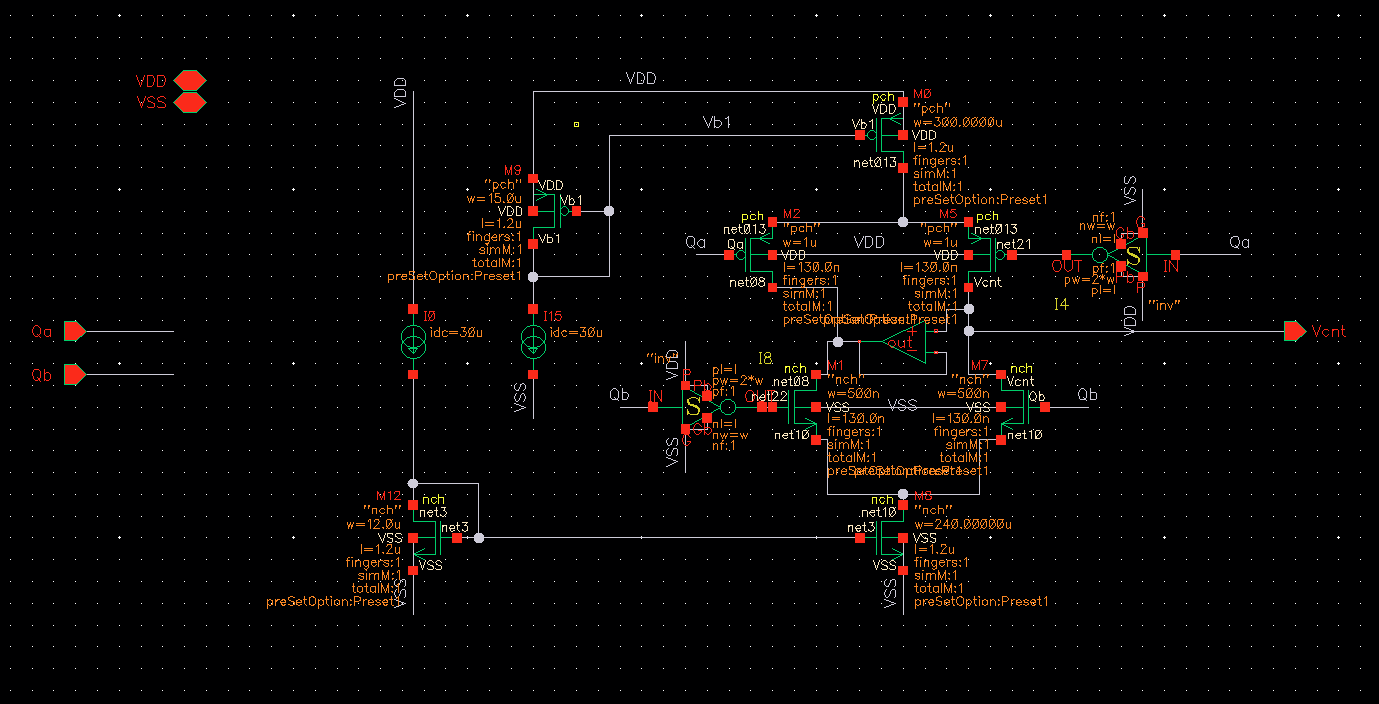
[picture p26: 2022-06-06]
Cadence/cp.png

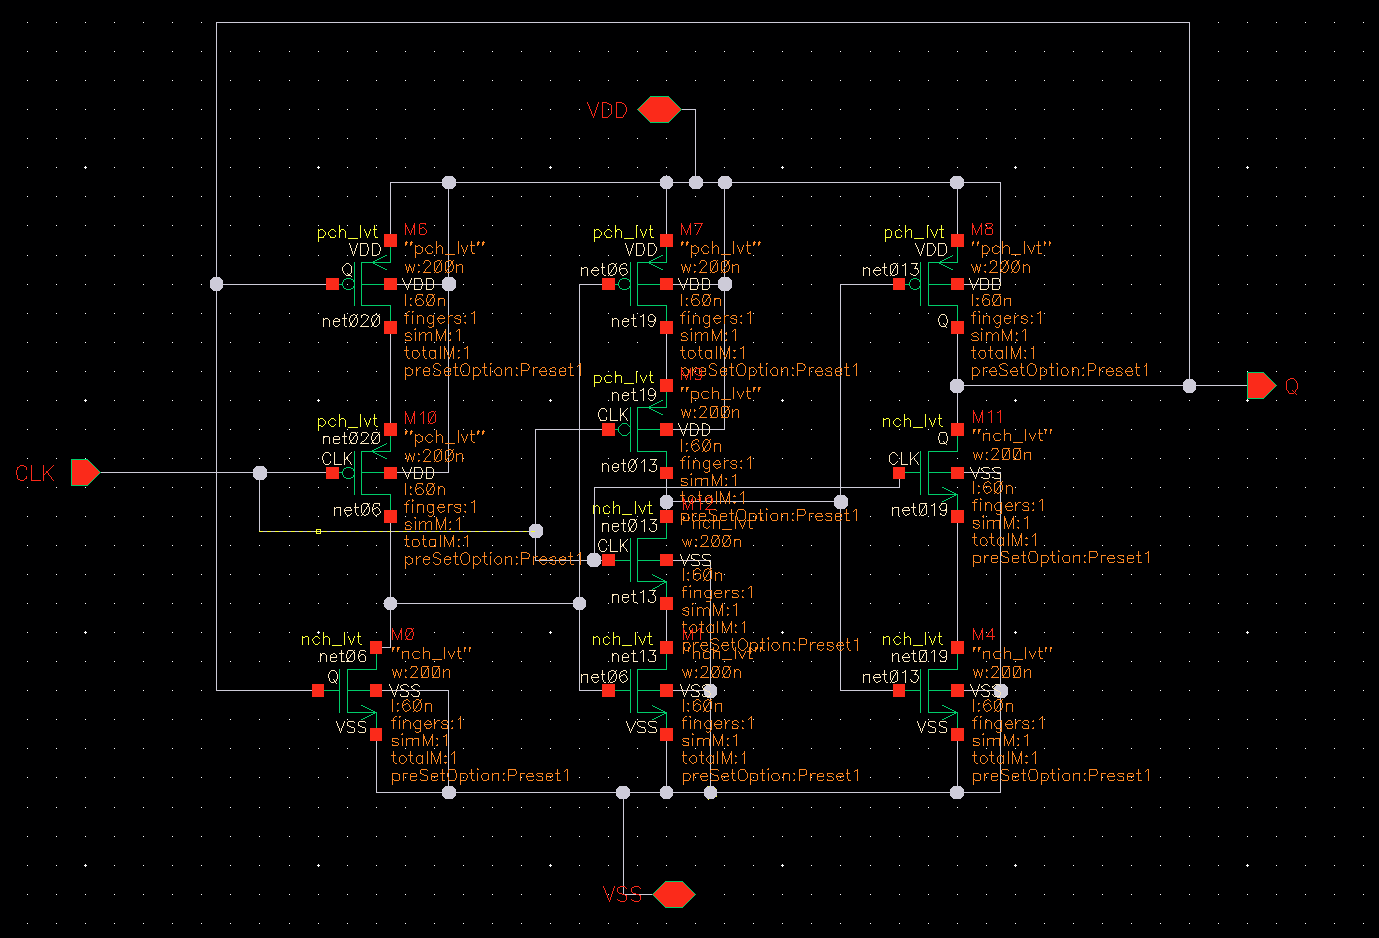
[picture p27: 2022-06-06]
Cadence/TSPC.png

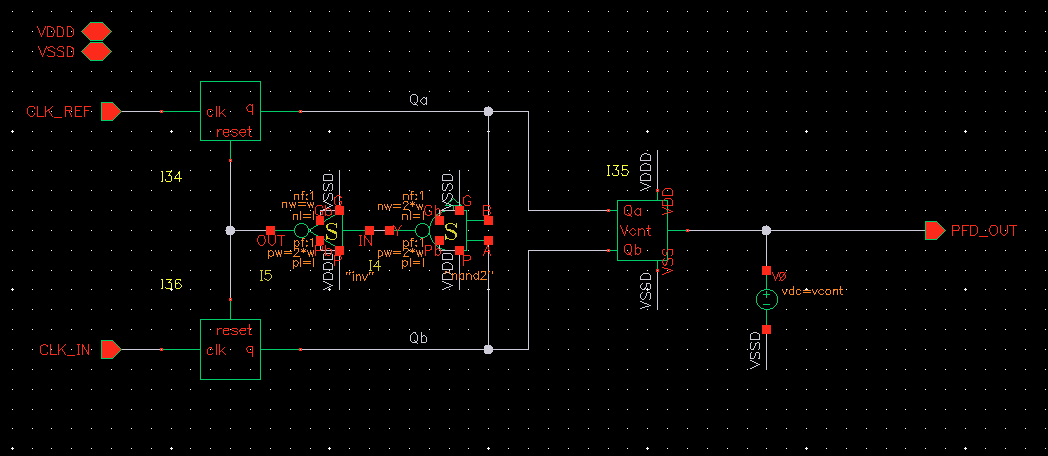
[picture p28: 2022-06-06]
Cadence/cp_tb.png

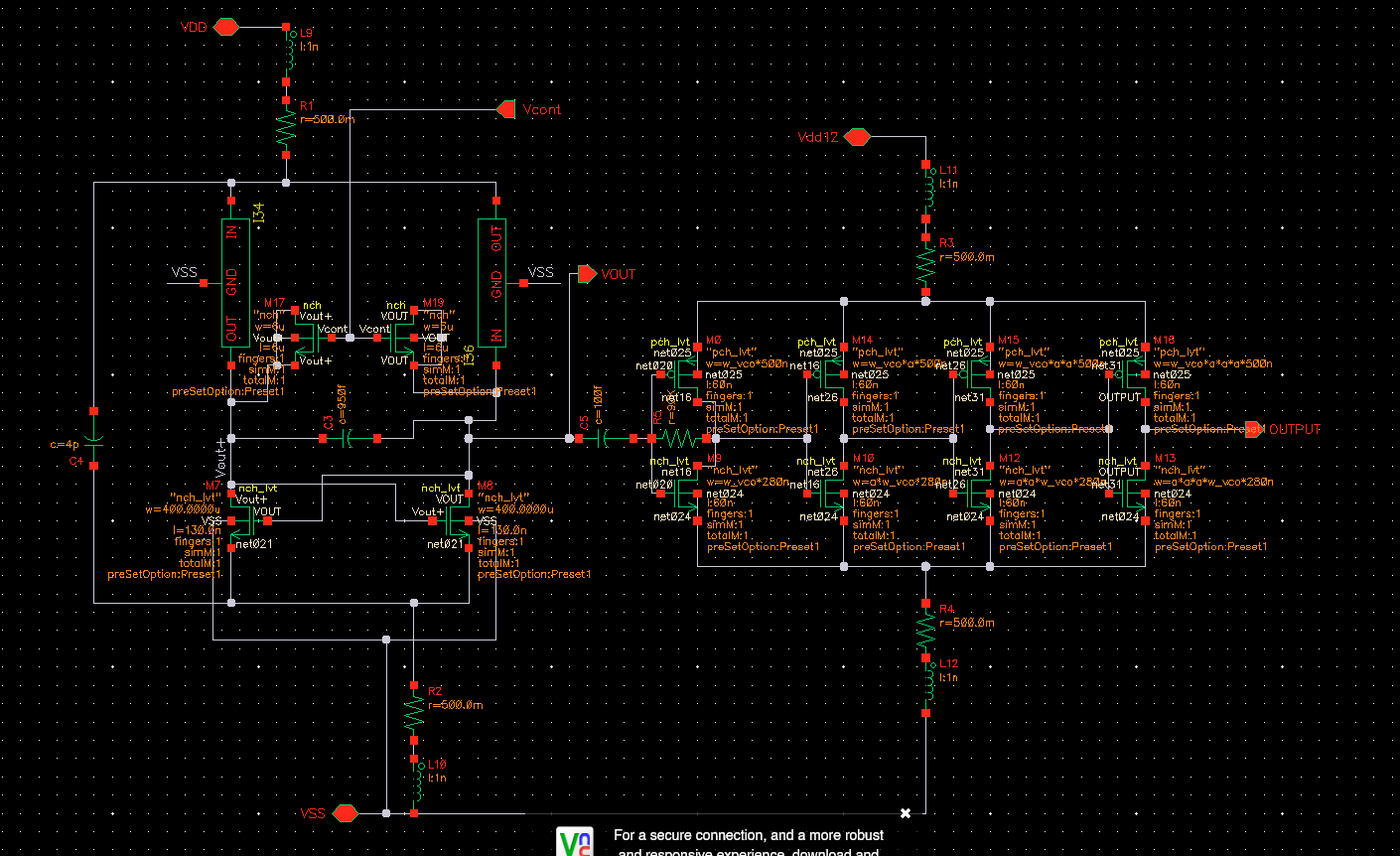
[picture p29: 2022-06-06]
Cadence/vco.png

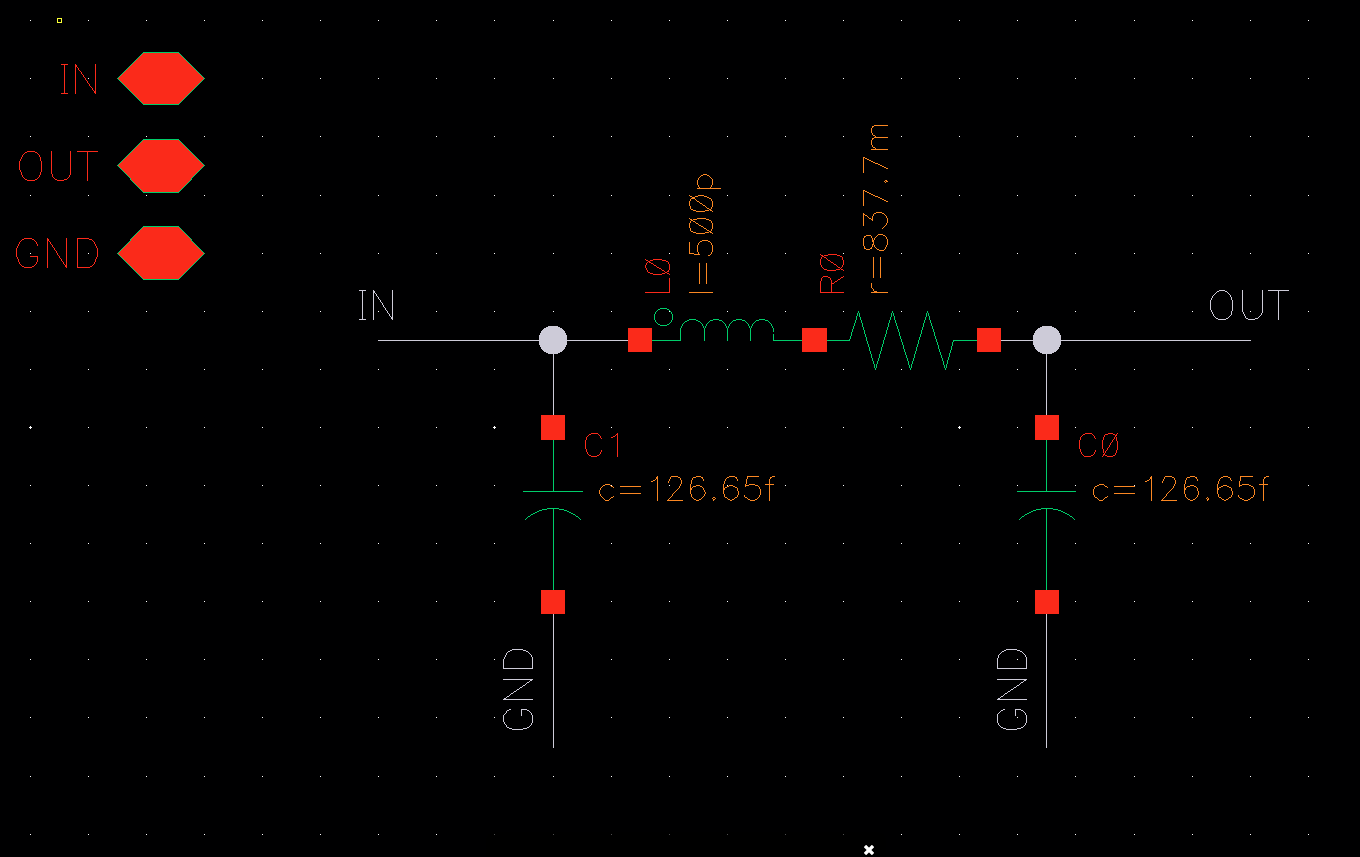
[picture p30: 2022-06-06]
Cadence/real_ind.png

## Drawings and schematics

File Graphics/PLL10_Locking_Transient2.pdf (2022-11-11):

### 10⁷ PLL Transient Behaviour

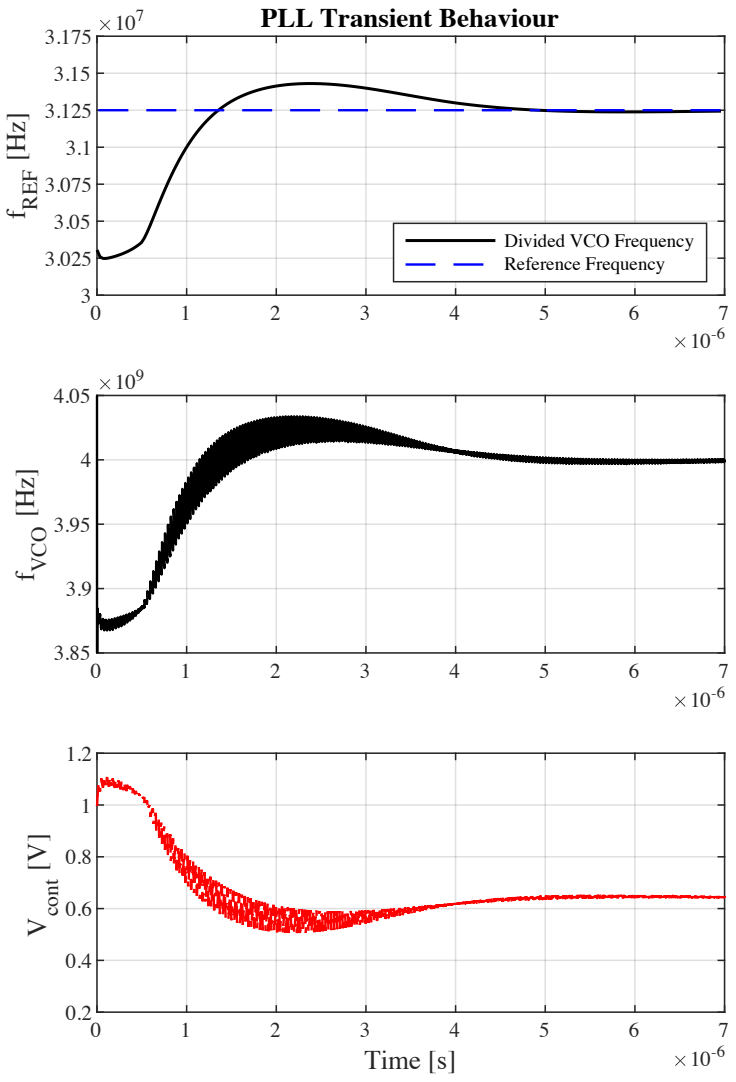
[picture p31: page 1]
fREF [Hz]; fVCO [Hz]; Time [s]; Vcont [V]

Divided VCO Frequency
Reference Frequency

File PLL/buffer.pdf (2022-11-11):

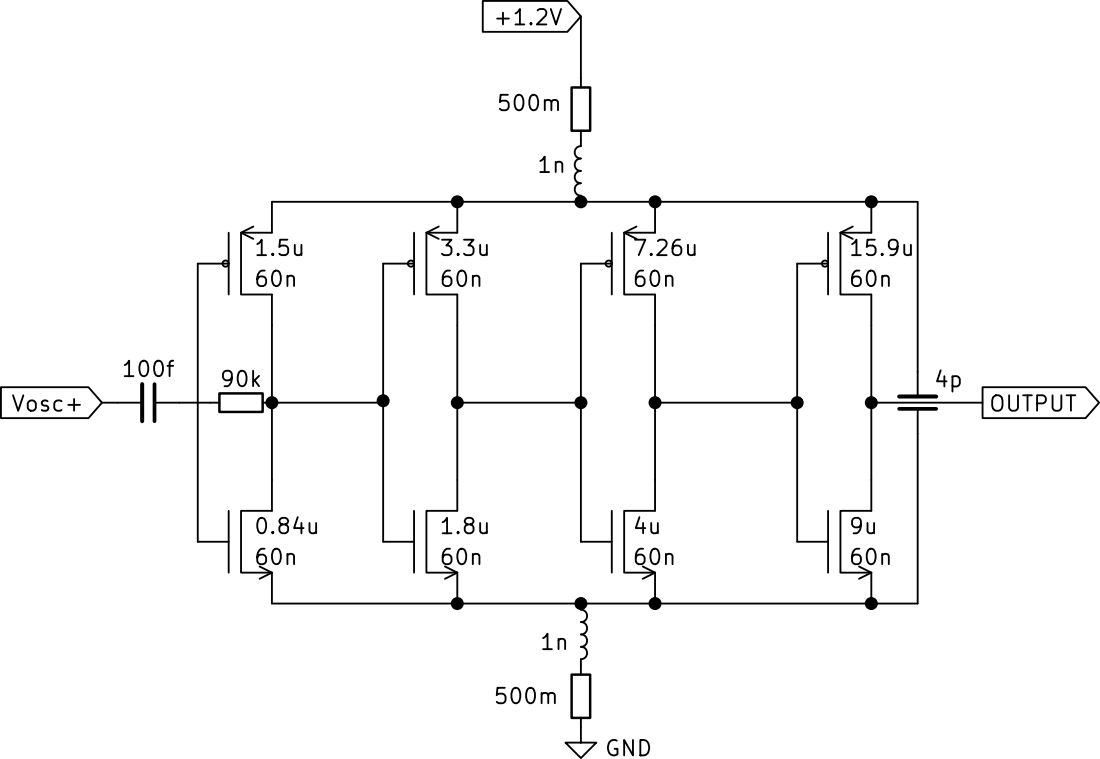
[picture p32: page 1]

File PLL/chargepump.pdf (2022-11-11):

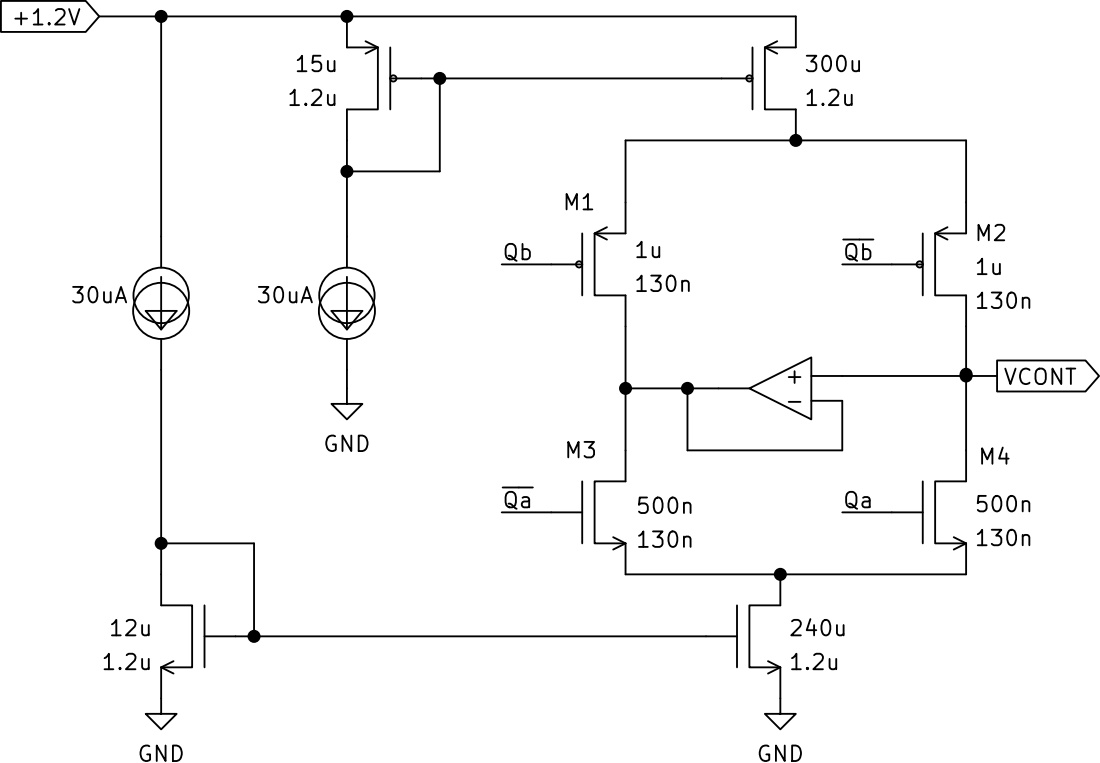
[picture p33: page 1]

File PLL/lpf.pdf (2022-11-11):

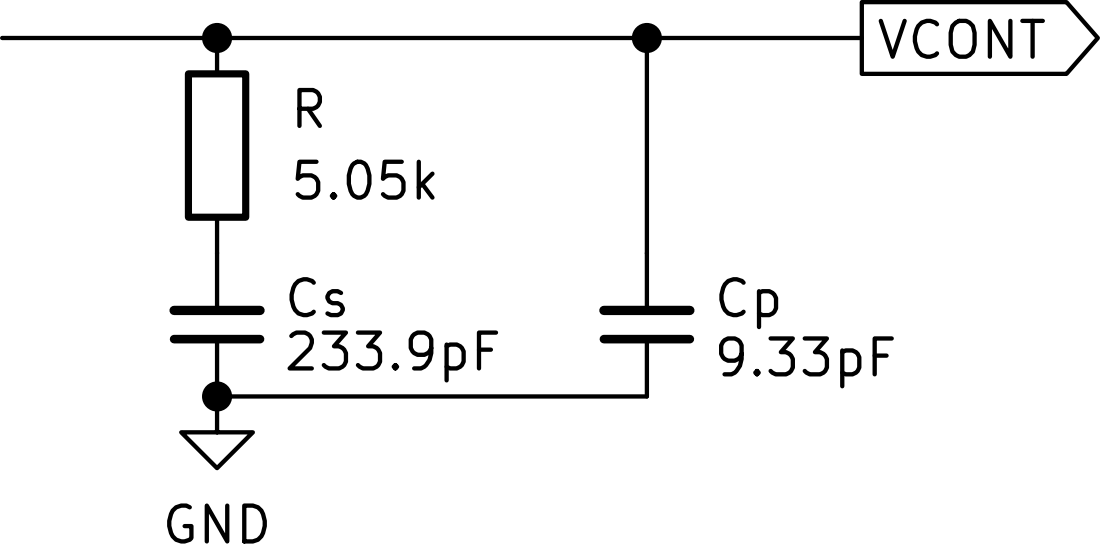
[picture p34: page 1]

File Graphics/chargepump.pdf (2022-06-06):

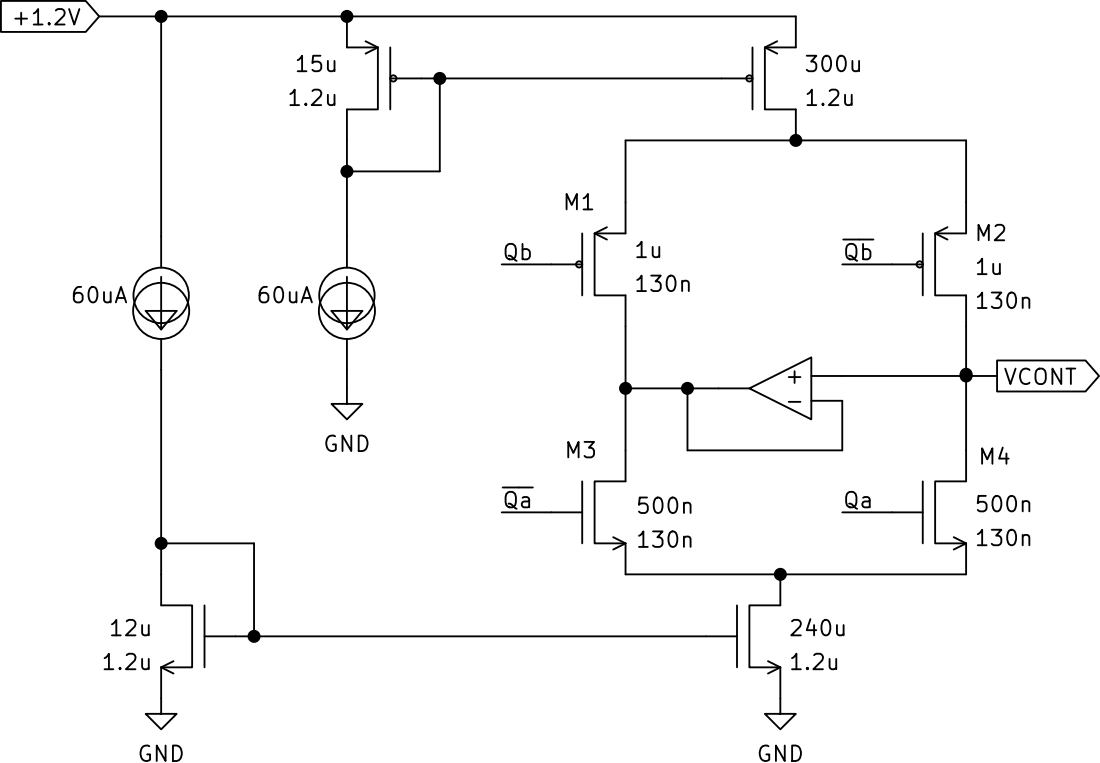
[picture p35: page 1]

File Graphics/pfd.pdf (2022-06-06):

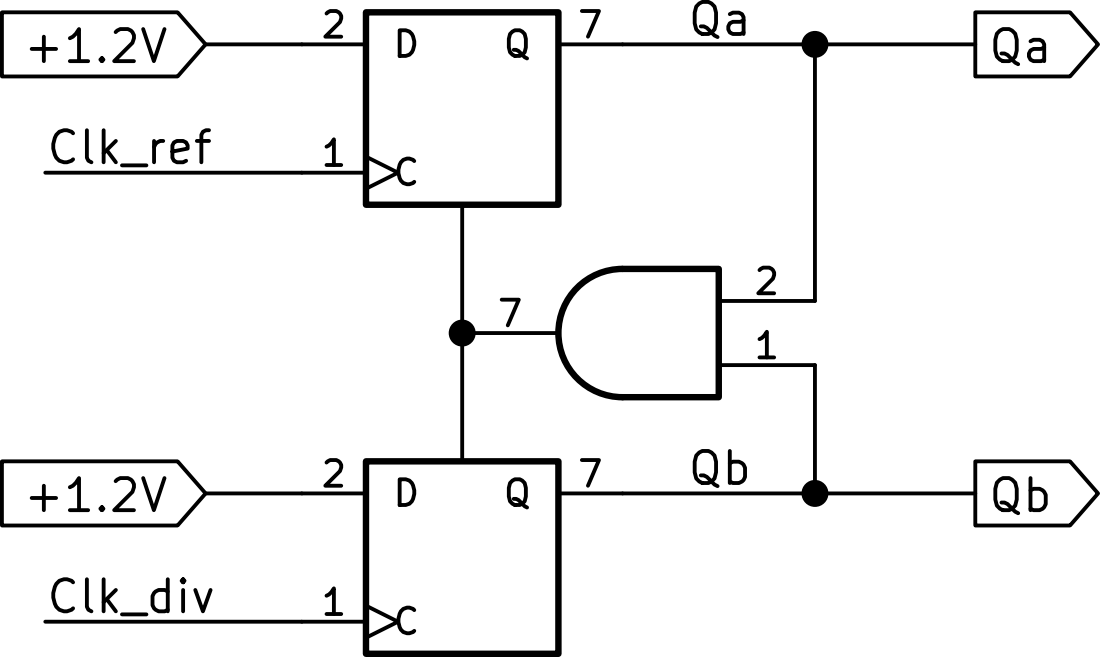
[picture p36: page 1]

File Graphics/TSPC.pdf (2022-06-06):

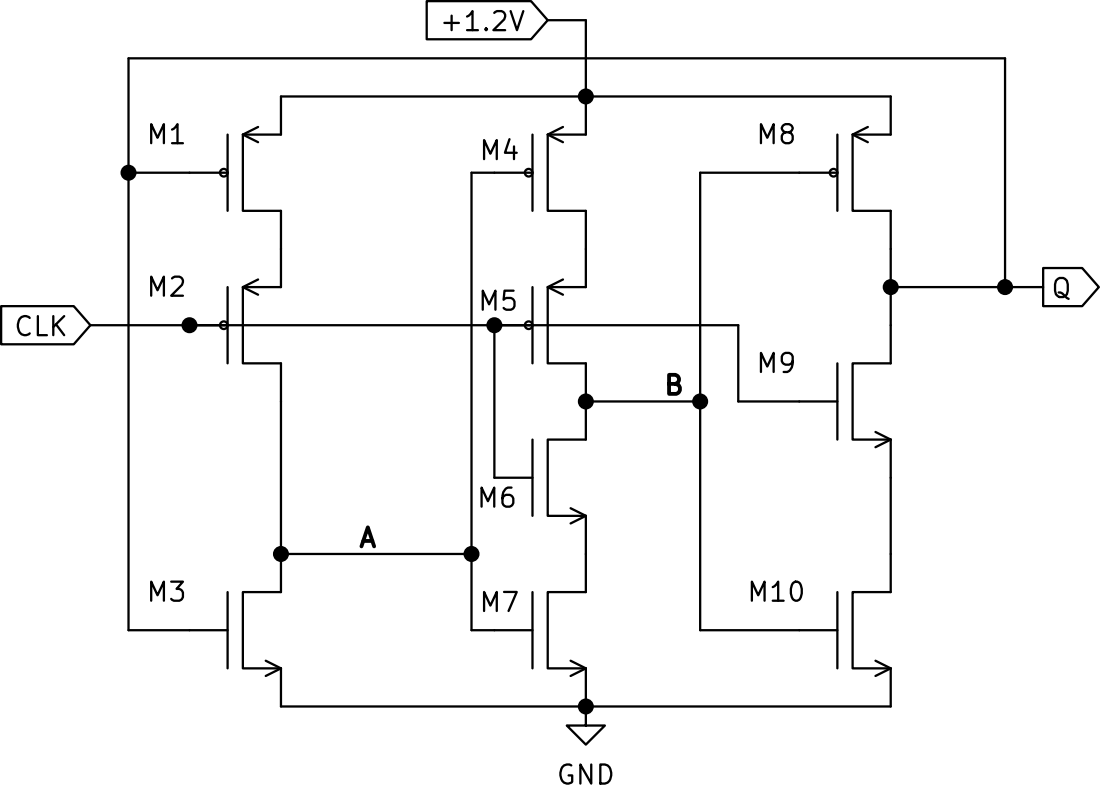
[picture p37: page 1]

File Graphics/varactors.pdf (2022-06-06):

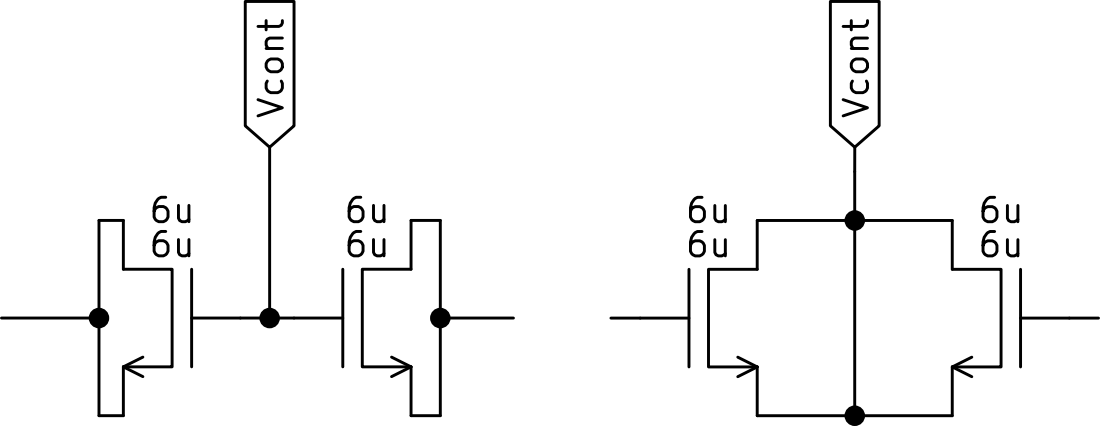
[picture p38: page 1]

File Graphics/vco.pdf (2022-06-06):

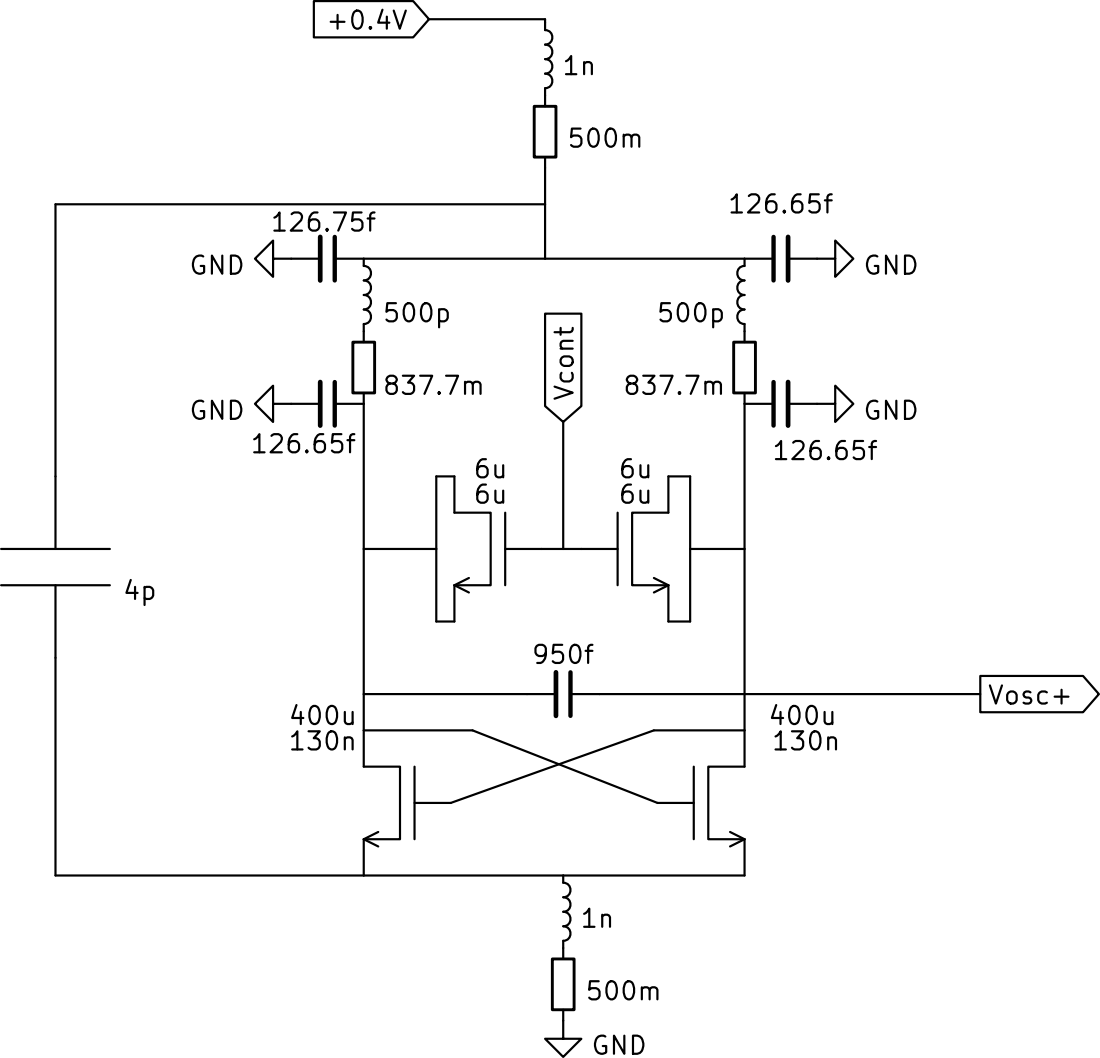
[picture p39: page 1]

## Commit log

2022-06-06 Charge pump test bench
    [CP_tb.kicad_pcb, CP_tb.kicad_sch]
2022-06-06 Screenshots from Cadence to translate schem. in KiCad
2022-06-06 Schematic for the SVGs
    [PLL.kicad_pcb, PLL.kicad_sch, pll.kicad_sch]
2022-06-06 Full-scale schematic of the PLL
2022-11-11 Added missing files
    [PLL.kicad_sch]
